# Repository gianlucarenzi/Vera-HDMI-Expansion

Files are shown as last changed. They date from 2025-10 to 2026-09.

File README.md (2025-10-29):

# VERA-HDMI-Expansion

<p align="center">
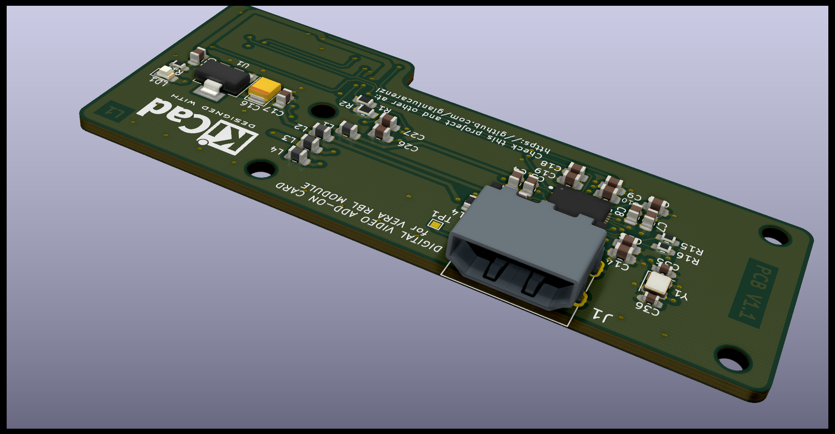
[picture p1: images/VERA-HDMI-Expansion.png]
VERA-HDMI-Expansion Board
  
</p>

<p align="center">
  An open-source HDMI expansion board for the <strong>VERA-MODULE-RBL</strong> video module.
</p>

---

## 📖 Overview

This project provides the complete design files for an HDMI expansion board specifically created for the **VERA-MODULE-RBL**. Its purpose is to convert the VERA module's native video signal into a standard HDMI output, allowing it to be easily connected to modern monitors and TVs.

The project was designed in KiCad, and all source files are included for viewing, modification, and manufacturing.

## ✨ Key Features

- 🔌 **Native HDMI Output:** Delivers a clean digital signal for maximum video quality.
- 🧩 **Compact Design:** Engineered to integrate seamlessly with the VERA-MODULE-RBL.
- ⚙️ **MS9288-Based:** Utilizes a dedicated chip for digital video to HDMI conversion.
- 📂 **Open Source:** All KiCad design files are freely available in this repository.

## 🛠️ How It Works

The board connects directly to the VERA-MODULE-RBL. The heart of the circuit is the **MS9288A/C** video converter chip, a specialized IC that receives digital video data from the VERA module, processes it, and encodes it into a TMDS (Transition-Minimized Differential Signaling) signal compatible with the HDMI standard.

This signal is then exposed via a standard HDMI connector, ready to be plugged into any modern display.

---

## 📚 Project Files & Documentation

### Schematic

The complete circuit schematic is available as a PDF for easy viewing.

- **[➡️ View Schematic (PDF)](VERA-HDMI-Expansion.pdf)**

### Bill of Materials (BOM)

An interactive HTML Bill of Materials (iBOM) is provided to simplify component identification and assembly.

- **[➡️ Open Interactive BOM](https://gianlucarenzi.github.io/Vera-HDMI-Expansion/BOM/ibom.html)**

---

## 🏭 Manufacturing

This repository contains all the necessary files for board production, including:
- KiCad source files (`.kicad_pcb`, `.sch`).
- Python scripts (`generate_cpl.py`, `jlcpcb-check-bom.py`) to automate the generation of Component Placement Lists (CPL) and to verify the BOM against JLCPCB's library.
- Manufacturing outputs in the `production/` directory.

### Board Renders

<table align="center">
  <tr>
    <td align="center"><strong>Top View</strong></td>
    <td align="center"><strong>Bottom View</strong></td>
  </tr>
  <tr>
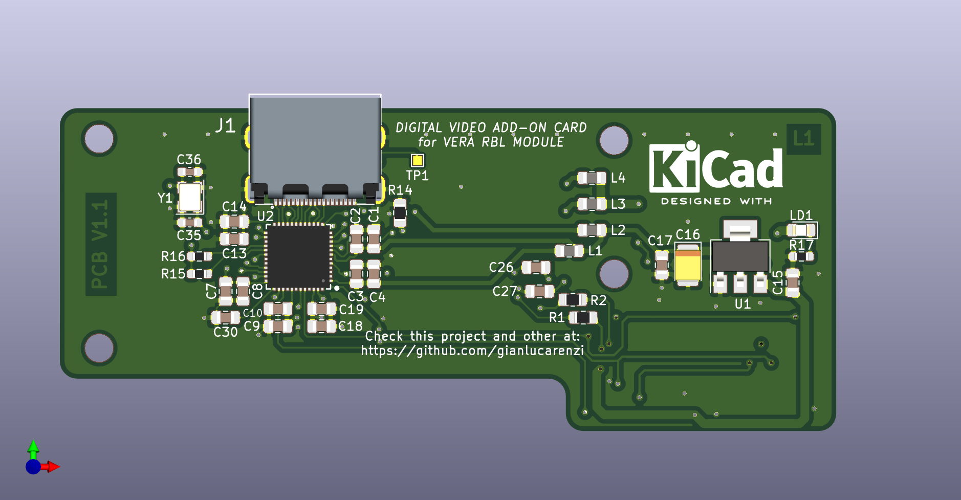
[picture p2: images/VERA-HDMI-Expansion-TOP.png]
Top View
    <td></td>
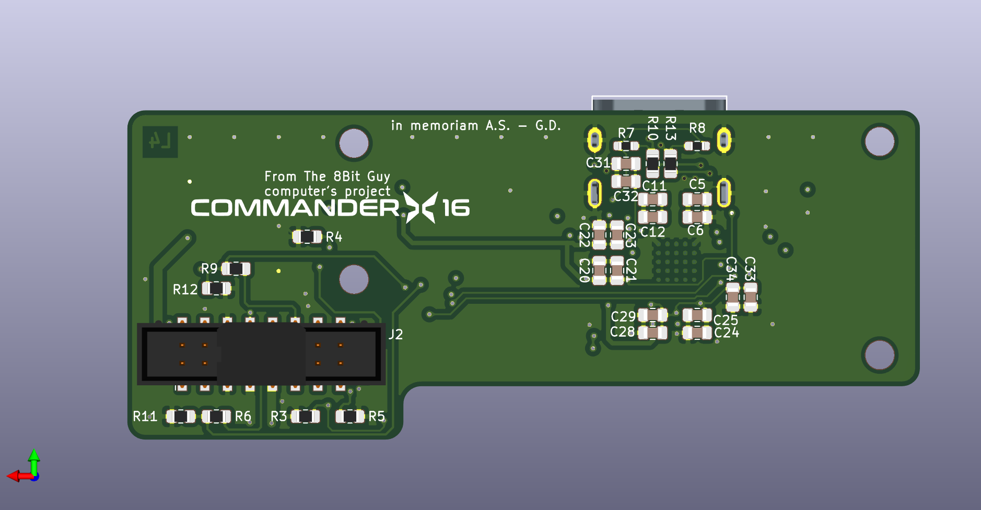
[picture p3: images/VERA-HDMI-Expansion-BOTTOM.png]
Bottom View
    <td></td>
  </tr>
</table>

---

## 📜 License

This project is released under the terms specified in the [LICENSE](LICENSE) file.

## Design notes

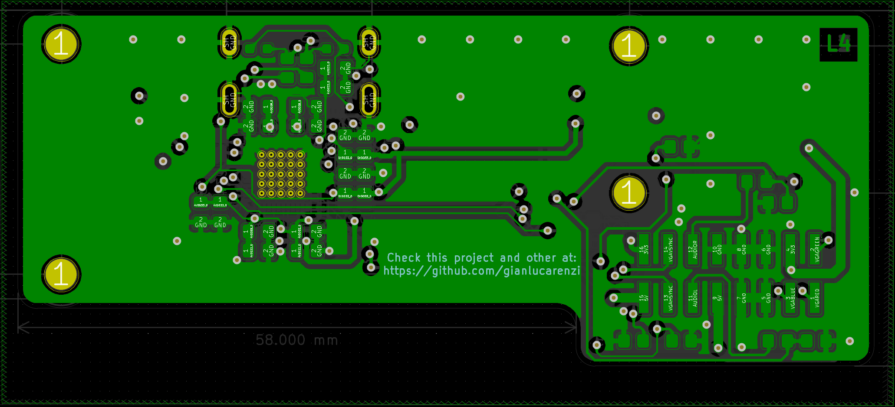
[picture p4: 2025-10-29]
images/B.Cu-L4.png

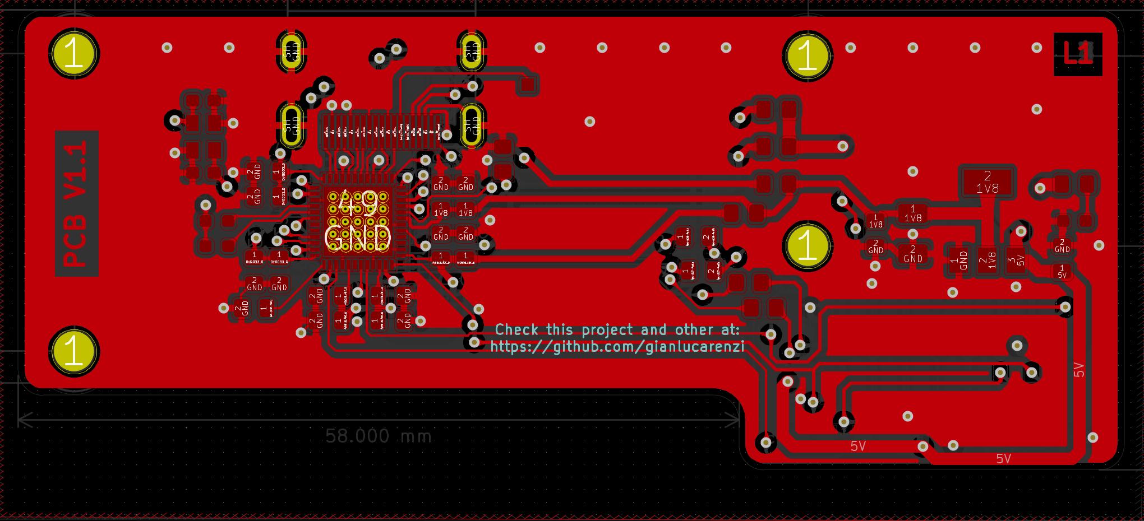
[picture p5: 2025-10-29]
images/F.Cu-L1.png

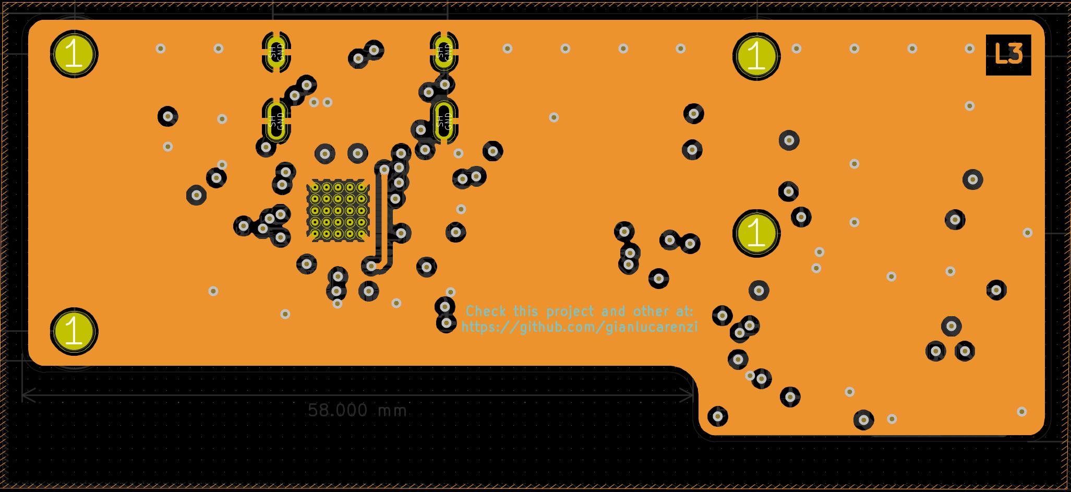
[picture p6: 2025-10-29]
images/GND-L3.png

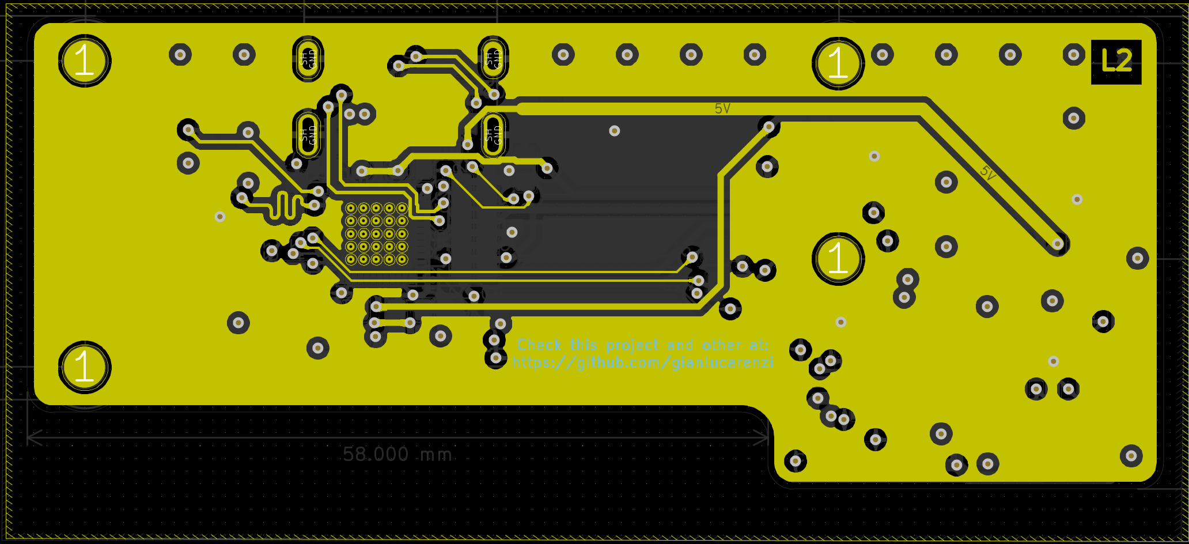
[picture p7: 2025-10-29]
images/POWER-L2.png

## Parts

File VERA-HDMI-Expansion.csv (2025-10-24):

Comment | Designator | Footprint | LCSC
10uF-20V | C16 | Capacitor_Tantalum_SMD:CP_EIA-3528-12_Kemet-T_Pad1.50x2.35mm_HandSolder | C8017
470nF | C26,C27 | Capacitor_SMD:C_0805_2012Metric_Pad1.18x1.45mm_HandSolder | C106843
22uF | C1,C3,C5,C7,C9,C11,C13,C18,C20,C22,C24,C28,C31,C33 | Capacitor_SMD:C_0805_2012Metric_Pad1.18x1.45mm_HandSolder | C86817
100nF | C2,C4,C6,C8,C10,C12,C14,C15,C17,C19,C21,C23,C25,C29,C30,C32,C34 | Capacitor_SMD:C_0805_2012Metric_Pad1.18x1.45mm_HandSolder | C840116
MountingHole | H1,H2,H3,H4 | MountingHole:MountingHole_3.2mm_M3
CONN_HDMI_A | J1 | RetroBitLab:CONN_HDMI-A | C720616
CONN_SMD_HEADER_BOX_02x08_Odd_Even_2.54mm | J2 | RetroBitLab:PinHeader_BOX_2x08_P2.54mm_Vertical_SMD | C2685064
FB080590R100MHZ850mA | L1,L2,L3,L4 | Inductor_SMD:L_0805_2012Metric_Pad1.15x1.40mm_HandSolder | C50325938
GREEN | LD1 | LED_SMD:LED_0805_2012Metric_Pad1.15x1.40mm_HandSolder | C84260
KiCAD Logo | LOGO1 | Symbol:KiCad-Logo2_6mm_SilkScreen
Commander X16 Project | LOGO2 | RetroBitLab:x16logo
1K | R14 | Resistor_SMD:R_0805_2012Metric_Pad1.20x1.40mm_HandSolder | C17513
2K7 | R7,R8,R15,R16 | Resistor_SMD:R_0603_1608Metric_Pad0.98x0.95mm_HandSolder | C491210
560R | R17 | Resistor_SMD:R_0603_1608Metric_Pad0.98x0.95mm_HandSolder | C114629
100R | R1,R2,R10,R13 | Resistor_SMD:R_0805_2012Metric_Pad1.20x1.40mm_HandSolder | C17408
75R | R3,R4,R5 | Resistor_SMD:R_0805_2012Metric_Pad1.20x1.40mm_HandSolder | C20142801
10K | R6,R9,R11,R12 | Resistor_SMD:R_0805_2012Metric_Pad1.20x1.40mm_HandSolder | C84376
TestPoint | TP1 | TestPoint:TestPoint_Pad_1.0x1.0mm
AMS1117-1.8 | U1 | Package_TO_SOT_SMD:SOT-223-3_TabPin2 | C6185
MS9288C | U2 | RetroBitLab:MS9288C | C2914316

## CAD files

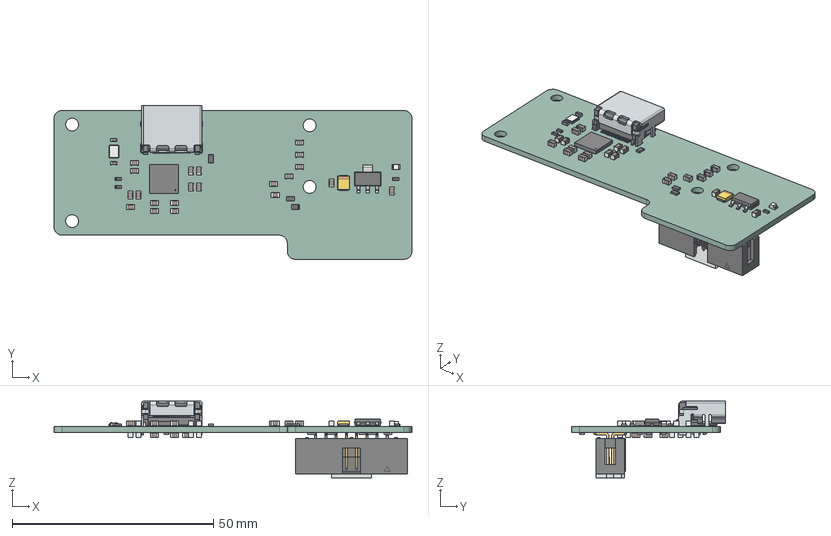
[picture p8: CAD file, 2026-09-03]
images/VERA-HDMI-Expansion.step
89.0 x 38.2 x 19.1 mm
C_0805_2012Metric x 33
CP_EIA-3528-12_Kemet-T
685119134923_Housing
685119134923_Shielding
685119134923_Pin1 x 10
685119134923_Pin2 x 9
L_0805_2012Metric x 4
R_0805_2012Metric x 12
R_0603_1608Metric x 5
SOT-223
ESP32-PICO-D4_EXP
LED_0805_2012Metric
6120xx20621_PIN x 16
6123xx20621_Cap
C_0603_1608Metric x 2
Crystal_SMD_EuroQuartz_MT-4Pin_3.2x2.5mm
VERA-HDMI-Expansion_PCB

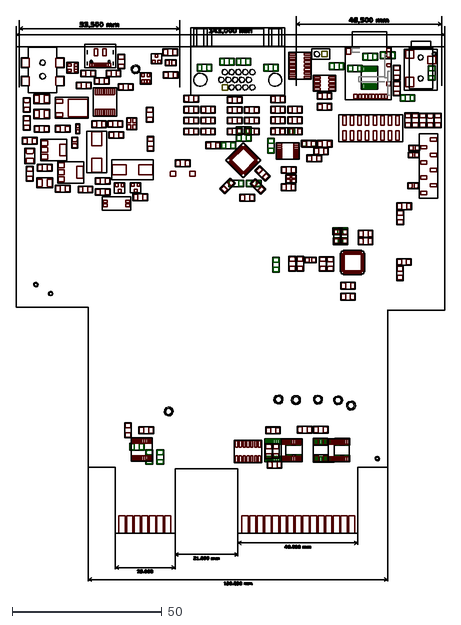
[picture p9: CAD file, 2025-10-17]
VERA-MODULE-RBL-brd.dxf
143.0 x 189.9

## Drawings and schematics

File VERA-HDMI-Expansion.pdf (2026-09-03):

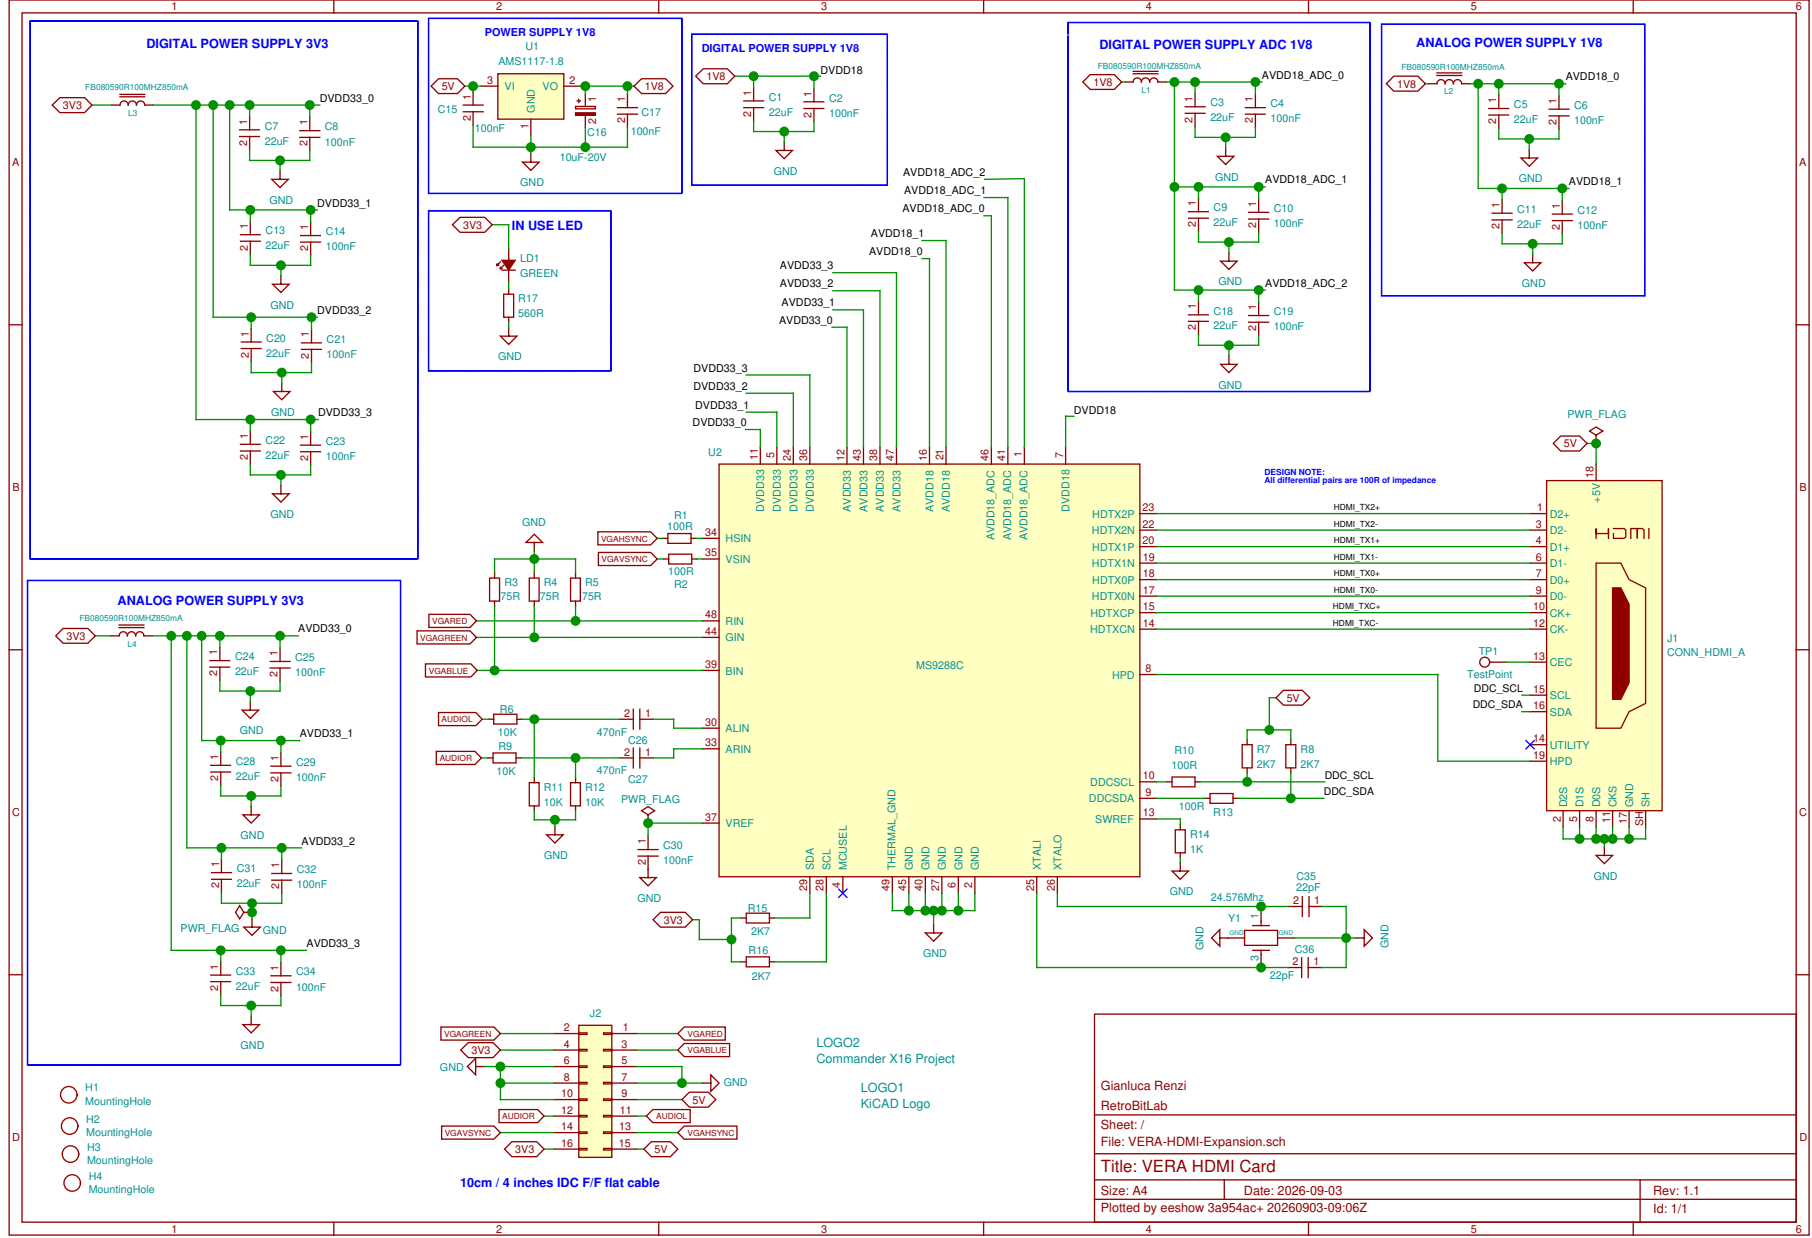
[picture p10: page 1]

DESIGN NOTE:
All differential pairs are 100R of impedance

Gianluca Renzi
RetroBitLab
Sheet: /
File: VERA-HDMI-Expansion.sch
Title: VERA HDMI Card

10cm / 4 inches IDC F/F flat cable

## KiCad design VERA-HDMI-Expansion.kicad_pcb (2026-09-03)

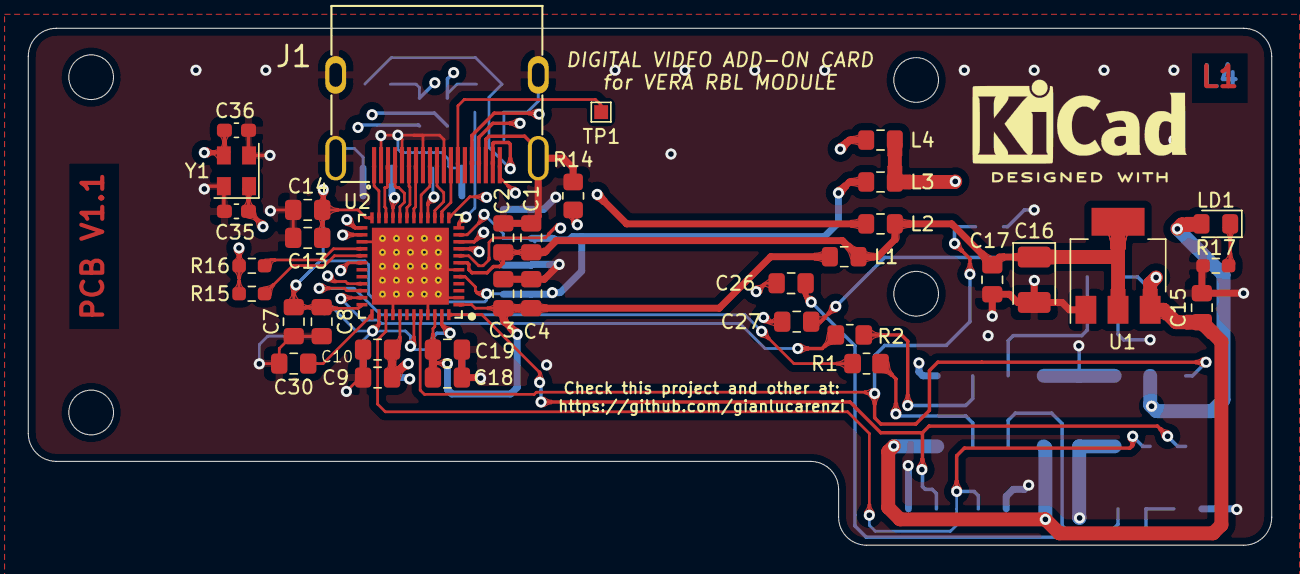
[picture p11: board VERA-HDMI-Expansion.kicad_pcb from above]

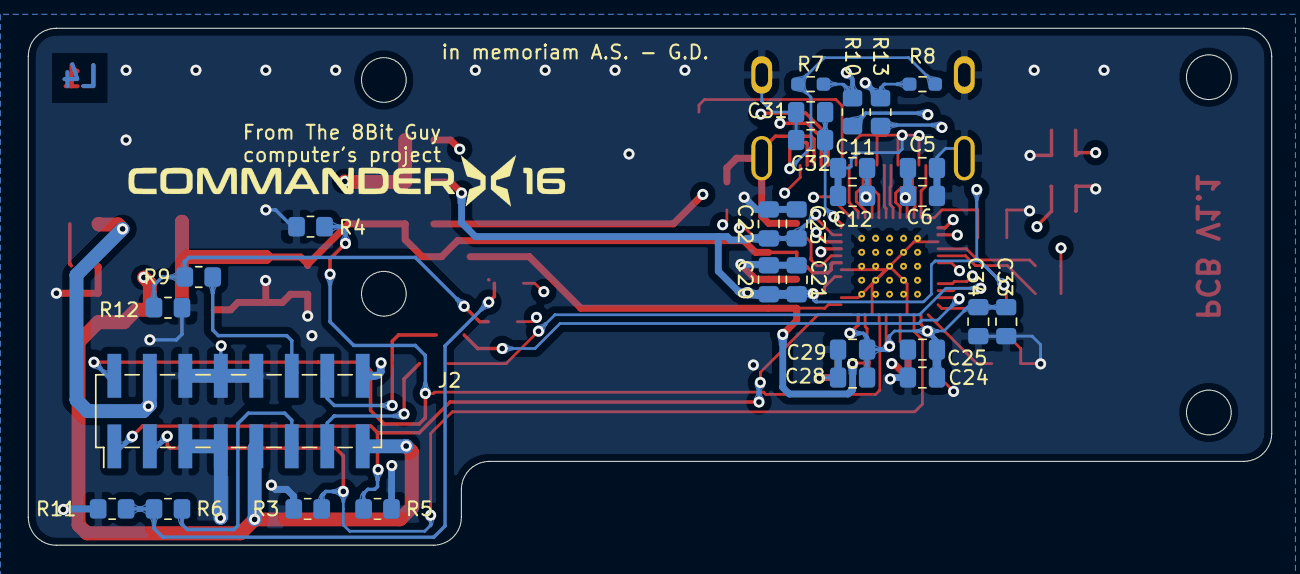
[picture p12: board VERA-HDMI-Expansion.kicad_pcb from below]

Board: 4 copper layers, 89.0 x 37.0 mm, 70 parts (29 on the bottom side), 42 nets.

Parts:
C1, C3, C5, C7, C9, C11, C13, C18, C20, C22, C24, C28, C31, C33: 22uF; C_0805_2012Metric_Pad1.18x1.45mm_HandSolder
C2, C4, C6, C8, C10, C12, C14, C15, C17, C19, C21, C23, C25, C29, C30, C32, C34: 100nF; C_0805_2012Metric_Pad1.18x1.45mm_HandSolder
C16: 10uF-20V; CP_EIA-3528-12_Kemet-T_Pad1.50x2.35mm_HandSolder
C26, C27: 470nF; C_0805_2012Metric_Pad1.18x1.45mm_HandSolder
C35, C36: 22pF; C_0603_1608Metric_Pad1.08x0.95mm_HandSolder
H1, H2, H3, H4: MountingHole; MountingHole_3.2mm_M3
J1: CONN_HDMI_A; CONN_HDMI-A
J2: CONN_SMD_HEADER_BOX_02x08_Odd_Even_2.54mm; PinHeader_BOX_2x08_P2.54mm_Vertical_SMD
L1, L2, L3, L4: FB080590R100MHZ850mA; L_0805_2012Metric_Pad1.15x1.40mm_HandSolder
LD1: GREEN; LED_0805_2012Metric_Pad1.15x1.40mm_HandSolder
LOGO1: KiCAD Logo; KiCad-Logo2_6mm_SilkScreen
LOGO2: Commander X16 Project; x16logo
R1, R2, R10, R13: 100R; R_0805_2012Metric_Pad1.20x1.40mm_HandSolder
R3, R4, R5: 75R; R_0805_2012Metric_Pad1.20x1.40mm_HandSolder
R6, R9, R11, R12: 10K; R_0805_2012Metric_Pad1.20x1.40mm_HandSolder
R7, R8, R15, R16: 2K7; R_0603_1608Metric_Pad0.98x0.95mm_HandSolder
R14: 1K; R_0805_2012Metric_Pad1.20x1.40mm_HandSolder
R17: 560R; R_0603_1608Metric_Pad0.98x0.95mm_HandSolder
TP1: TestPoint; TestPoint_Pad_1.0x1.0mm
U1: AMS1117-1.8; SOT-223-3_TabPin2
U2: MS9288C
Y1: 24.576Mhz; Crystal_SMD_EuroQuartz_MT-4Pin_3.2x2.5mm

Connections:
1V8: C1.1, C2.1, C16.1, C17.1, L1.1, L2.1, U1.2, U2.7
3V3: J2.4, J2.16, L3.1, L4.1, LD1.2, R15.1, R16.1
5V: C15.1, J1.18, J2.9, J2.15, R7.1, R8.1, U1.3
/AVDD18_0: C5.1, C6.1, C11.1, C12.1, L2.2, U2.16, U2.21
/AVDD18_ADC_0: C3.1, C4.1, C9.1, C10.1, C18.1, C19.1, L1.2, U2.1, U2.41, U2.46
/AVDD33_0: C24.1, C25.1, C28.1, C29.1, C31.1, C32.1, C33.1, C34.1, L4.2, U2.12, U2.38, U2.43, U2.47
/DDC_SCL: J1.15, R7.2, R10.1
/DDC_SDA: J1.16, R8.2, R13.1
/DVDD33_0: C7.1, C8.1, C13.1, C14.1, C20.1, C21.1, C22.1, C23.1, L3.2, U2.5, U2.11, U2.24, U2.36
/HDMI_TX0+: J1.7, U2.18
/HDMI_TX0-: J1.9, U2.17
/HDMI_TX1+: J1.4, U2.20
/HDMI_TX1-: J1.6, U2.19
/HDMI_TX2+: J1.1, U2.23
/HDMI_TX2-: J1.3, U2.22
/HDMI_TXC+: J1.10, U2.15
/HDMI_TXC-: J1.12, U2.14
AUDIOL: J2.11, R6.1
AUDIOR: J2.12, R9.1
GND: C1.2, C2.2, C3.2, C4.2, C5.2, C6.2, C7.2, C8.2, C9.2, C10.2, C11.2, C12.2, C13.2, C14.2, C15.2, C16.2, C17.2, C18.2, C19.2, C20.2, C21.2, C22.2, C23.2, C24.2, C25.2, C28.2, C29.2, C30.2, C31.2, C32.2, C33.2, C34.2, C35.1, C36.1, J1.2, J1.5, J1.8, J1.11, J1.17, J1.SH, J2.5, J2.6, J2.7, J2.8, J2.10, R3.1, R4.1, R5.1, R11.1, R12.1, R14.2, R17.2, U1.1, U2.2, U2.6, U2.27, U2.40, U2.45, U2.49, Y1.2, Y1.4
unnamed: C26.1, U2.30
unnamed: C26.2, R6.2, R11.2
unnamed: C27.1, U2.33
unnamed: C27.2, R9.2, R12.2
unnamed: C30.1, U2.37
unnamed: C35.2, U2.26, Y1.1
unnamed: C36.2, U2.25, Y1.3
unnamed: J1.13, TP1.1
unnamed: J1.19, U2.8
unnamed: LD1.1, R17.1
unnamed: R1.1, U2.34
unnamed: R2.1, U2.35
unnamed: R10.2, U2.10
unnamed: R13.2, U2.9
unnamed: R14.1, U2.13
unnamed: R15.2, U2.29
unnamed: R16.2, U2.28
VGABLUE: J2.3, R3.2, U2.39
VGAGREEN: J2.2, R4.2, U2.44
VGAHSYNC: J2.13, R1.2
VGARED: J2.1, R5.2, U2.48
VGAVSYNC: J2.14, R2.2

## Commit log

2025-10-23 Removed H2 Mounting Hole. PCB is bigger to accomodate the new position of H1 (16mm x 96mm from the right side of the bottom board)
    [VERA-XE-HDMI-Expansion.csv, VERA-XE-HDMI-Expansion.sch]
2025-10-23 Automatically generate the PDF from schematics.
2025-10-29 Removed. Not needed now
    [VERA-XE-HDMI-Expansion-XE-v0.1a-JLCPCB-BOM.csv, VERA-XE-HDMI-Expansion-XE-v0.2a-JLCPCB-BOM.csv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]
2025-10-29 New pos file
    [VERA-XE-HDMI-Expansion_cpl_bot.csv, VERA-XE-HDMI-Expansion_cpl_top.csv]
2025-10-29 Autogenerated v1.1
    [VERA-XE-HDMI-Expansion.kicad_pcb]
2025-10-29 Updated & Autogenerated v1.1
    [VERA-XE-HDMI-Expansion.step]
2025-10-29 Providing the kicad-cli shell script for Flatpak KiCAD 7+ version. Put the script into a reachable folder in PATH for the shell.
2025-10-29 Autogenerated v1.1+
    [VERA-XE-HDMI-Expansion.step]
2025-10-29 Removed (now the project does not include 'XE' string)
    [VERA-XE-HDMI-Expansion.csv, VERA-XE-HDMI-Expansion.dsn, VERA-XE-HDMI-Expansion.kicad_pcb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]
2025-10-29 To be checked
    [VERA-HDMI-Expansion.csv, VERA-HDMI-Expansion.dsn, VERA-HDMI-Expansion.kicad_pcb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]
2025-10-29 Added (now the project does not include 'XE' string)
    [VERA-HDMI-Expansion.step]
2025-10-29 New date
    [VERA-HDMI-Expansion.sch]
2025-10-29 Removed. Must be launched from PCBNEW when ready for production. After the output_job.sh should be launched.
    [VERA-HDMI-Expansion-B_Cu.gbl, VERA-HDMI-Expansion-B_Mask.gbs, VERA-HDMI-Expansion-B_Paste.gbp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]
2025-10-29 Saved after a production plot run
    [VERA-HDMI-Expansion.kicad_pcb]
2025-10-29 Ignored. The Gerbers must be created into PCBNEW, and then launched the output_job.sh script
2025-10-29 24.576Mhz Crystal Oscillator added
    [VERA-HDMI-Expansion.kicad_pcb, VERA-HDMI-Expansion.sch]
2026-09-03 Fix eeplot PDF export: keep each schematic sheet's own page size
    eeplot forced every page of the exported PDF to the size of the largest
    sheet, anchoring smaller sheets top-left instead of keeping their native
    paper size (same fix as applied in Vera-Module-RBL-XE). Patch
    record_wipe()/cr_pdf_end() so each page is sized and offset from its own
    bounding box, and wire patch application into output_job.sh's eeplot
    build/update steps. Regenerated VERA-HDMI-Expansion.pdf with the fix.
2026-09-03 Updated Crystal Oscillator Symbol from RetroBit Library
    [VERA-HDMI-Expansion.sch]
2026-09-03 UpdateUpdated Crystal Oscillator Symbol from RetroBit Library. No actual changes for PCB and BOM/CPL
    [VERA-HDMI-Expansion.kicad_pcb, VERA-HDMI-Expansion.step]
2026-11-02 output_job.sh: XML netlist made by kicadcli, STEP by kicad2step, VRML by FreeCAD
    utilities/kicadcli (command line tool for KiCad 5 schematics) is installed
    into $HOME/bin when it is not in the PATH; the XML netlist for the BOM is
    made from the schematic at every run (no more manual 'Generate BOM' in
    eeschema, so the BOM can no longer miss newer parts).
    STEP: kicad2step of KiCad 5 (outside the flatpak, so the KiCad 5 3D models
    are found), board recoloured to the solder mask green.
    VRML: converted from that STEP with FreeCAD on Xvfb (utilities/step2wrl.py),
    colours kept, placed like the KiCad VRML. kicad-cli stays as fallback.
2026-11-02 JLCPCB stock check; R3-R5 75R now C317238
    check_jlcpcb_stock.sh [-n BOARDS] (as in Vera-Module-RBL-XE): the JLCPCB BOM
    is built from the schematic (kicadcli XML, the grouped JLCPCB XSL) in a
    temporary folder and jlcpcb-stock-check.py checks every LCSC code against
    the live JLCPCB parts library and the stock for N boards.
    R3, R4, R5: C20142801 had only 7 pieces left, now KOA RK73H2ATTD75R0F
    C317238 (same 75R 250mW 1%, as in RetroBitLab-Library CRES0805).
2026-11-02 v1.1 outputs regenerated by output_job.sh: BOM with Y1, C35, C36 and the new 75R
    The XML is now made from the schematic, so the BOM finally has the 24.576
    MHz crystal Y1 (C41383247) and C35/C36 22pF (C105620) added in September,
    and R3-R5 with C317238. STEP by kicad2step and VRML by FreeCAD, with all
    the 3D models.
2026-11-04 J2 is now a bottom-side 2x08 socket (C3975153) aligned to the VERA module J1
    - VERA-HDMI-Expansion.sch: J2 is CONN_SMD_02x08_Odd_Even_2.54mm with the
    PinSocket_2x08_P2.54mm_Vertical_SMD_Bottom footprint (LCSC C3975153)
    - J2 moved to (180.39, 105.44) over the module J1 (DXF on Eco1.User),
    attached B.Cu tracks moved with it, 45 degree joints kept
    - H3/H4 moved to (170, 95.4) and (170, 79.9) to match the module holes
    (H4-H3 was 15.3 mm instead of 15.5 mm)
    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
2026-11-04 output_job.sh plots Gerbers and drill files, v1.1 outputs regenerated
    - generate_gerbers.py and run_pcbnew.sh from Vera-Module-RBL-XE: Gerbers
    and drill files plotted with the KiCad 5 pcbnew module and the board plot
    settings, production/ emptied first (REFILL_ZONES=1 refills the zones
    without writing the board); drill files in mm, as before
    - clean_virtual.sh gets the board with --pcb: given as a positional
    argument it was rewritten as a CSV (blank lines dropped)
    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
2026-11-04 Mechanical assembly on the VERA-MODULE-RBL-XE: 3D model and mechanical BOM
    - images/VERA-XE-HDMI-assembly.step (STEP AP214) and .FCStd (FreeCAD 0.19):
    XE module + HDMI board on four 14 mm M3 F/F standoffs with M3x6 screws,
    J2 (HCTL PM254-2-08-S-8.5, 8.5 mm) plugged into J1 (HanXia JN2.54-2x8P)
    - Documentation/MECHANICAL-BOM.md: parts, hole positions, stack heights
    (pin engagement ~3.5 mm, DB15 clearance ~0.1 mm), assembly steps
    - README: Mechanical Assembly section
    - Git LFS for the assembly STEP and the FreeCAD files
2026-11-04 output_job.sh: interactive BOM generated with the other outputs
    - generate_ibom.py: runs the InteractiveHtmlBom plugin without pcbnew's
    GUI (console wx app, no display needed) and loads ibom.config.ini as the
    plugin started from pcbnew does (its own command line ignores the ini)
    - output_job.sh: BOM/ibom.html from the saved board after the Gerbers
    - BOM/ibom.html regenerated from the current board
2026-11-04 WORKFLOW and fastroute tools as in VERA-MODULE-RBL-XE/-C64
    - WORKFLOW.md/.tex/.pdf: from the schematic to the JLCPCB order, adapted to
    this board (single sheet, BOM by kicadcli + xsltproc, In1.Cu mixed,
    In2.Cu GND plane, ibom in BOM/, production/ not in the repository);
    PDF by tools/produce-pdf-from-tex.sh
    - tools/: route_incremental.sh (missing connections only, existing wiring
    kept; INNER_FALLBACK=1 uses the inner layers as a last resort) and
    optimize_new.sh (optimizer only on wiring added after a commit), with
    their helpers; same files as in the VERA-MODULE-RBL boards, board and
    layers found by board_info.py
    - .gitignore: the .dsn/.ses exchange files leave the repository (20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
2026-11-04 J1 shield to GND, missing connections routed, v1.1 outputs regenerated
    - schematic: J1 (HDMI) shield SH back on GND after the CONN_HDMI_A symbol
    change in RetroBitLab-Library (its wire no longer reached the moved pin);
    the four shell pads join the GND pours of F.Cu, B.Cu and In2.Cu
    - PCB: the 3 connections left by the J2 change routed (3V3 to J2-4,
    VGAGREEN to J2-2, Net-(C26-Pad2) to R11-2); ratsnest 0, PCB matches
    the schematic
    - output_job.sh 1.1: netlist XML, CPL, PDF, interactive BOM, STEP/VRML and
    layer images regenerated
    - .gitignore: *.sch-bak
2026-11-04 Layer images regenerated, PCB saved again
    - images/*-L1..L4.png: copper layer images of the current board
    - VERA-HDMI-Expansion.kicad_pcb: saved again by pcbnew, footprint graphics
    and pads only written in a different order (same content; PCB matches
    the schematic, ratsnest 0)
